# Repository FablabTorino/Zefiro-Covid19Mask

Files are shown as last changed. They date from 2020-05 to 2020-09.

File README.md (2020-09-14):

# Zefiro-Covid19Mask

<p style="text-align: left;"><span style="font-family: Helvetica;"><strong><span style="font-size: 16px;">Edited by:</span><span style="font-size: 18px;">&nbsp;</span></strong></span><span style="font-family: Helvetica; font-size: 14px;">Asja Aulisio,&nbsp;</span><span style="font-size: 14px;"><span style="font-family: Helvetica;">Stella Bellisario, Dario Bortolotti, Eva Vanessa Bruno, Alessandro Campanella, Francesca Cappa, Federico Citarda, Martina Gargiulo Pozzo, Davide Mercenati, Roberto Montarolo, &nbsp;</span></span><span style="font-family: Helvetica; font-size: 14px;">Fabiana Rovera</span></p>
<p style="text-align: left;"><span style="font-family: Helvetica;"><strong><span style="font-size: 16px;">Supervisors:&nbsp;</span></strong><span style="font-size: 14px;">Fabrizio Alessio (Councilor Fablab Torino),&nbsp;</span></span>
    <font face="Helvetica"><span style="font-size: 14px;">Fabrizio Valpreda (Prof. and Scientific director virtuaLAB - Politecnico di Torino),&nbsp;</span></font><span style="font-size: 14px;"><span style="font-family: Helvetica;">Alessandro Dentis&nbsp;</span></span><span style="font-size: 14px;"><span style="font-family: Helvetica;">(Technical manager virtuaLAB -&nbsp;</span></span><span style="font-family: Helvetica; font-size: 14px;">Politecnico di Torino)</span>
</p>

<p style="text-align: left;"><span style="font-family: Helvetica;"><span style="font-size: 16px;"><strong>Contacts</strong></span><span style="font-family: Helvetica; font-size: 16px;"><strong style="font-weight: 700;">: <span style="font-family: Helvetica; font-size: 14px;"></span></strong><span style="font-family: Helvetica; font-size: 14px;"></span><span style="font-family: Helvetica; font-size: 14px;"><a href="mailto:covid@fablabtorino.org,">covid@fablabtorino.org,</a> <span style="font-family: Helvetica;"><a href="mailto:virtualab@polito.it">virtualab@polito.it</a></span></span></span></span></p>

<p>&nbsp;&nbsp;</p>

<a href="https://ibb.co/vPhq9wr">3279467-orig</a>
<a href="https://ibb.co/tzwNXNw">Schermata-2020-05-14-alle-22-59-36</a>

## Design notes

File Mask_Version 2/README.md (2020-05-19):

# FABRIC-FRAME
## FRAME-FACE SHIELD

__Problem__: Now it's just glued    
__Need__: Fixing with mask, reversible, guaranteeing insolation and 3D printing    

## DIFFUSER
__Problem__: Fragile diffuser-valve connection    
__Need__: Improve the connection system with the valve     

- Study of printing parameters and thicknesses. Guarantee resistance with suitable thicknesses. 
- What are the stresses on the frame? Does it need a large thickness or a thin one with designed filling?
- Improve the elastic distribution system.
- Improve printability: problem with printers with a small printing plate.
- Improve ergonomics

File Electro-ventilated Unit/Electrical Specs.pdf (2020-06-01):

# Zefiro

### Descrizione:

Componenti elettriche ed elettroniche necessarie al funzionamento di un respiratore PAPR. Le componenti principali saranno:
- ventole, comprese di motore e soffiante,
- batterie (per l’alimentazione delle ventole e dell’elettronica di controllo),
- sensore di pressione,
- sistema di controllo del voltaggio delle batterie,
- attuatori acustici per segnalazioni,
- attuatori luminosi (LED) per segnalazioni,
- interfaccia di controllo e parametrizzazione del funzionamento

I requisiti principali di funzionamento possono essere descritti con:
- le batterie devono essere adatte ad alimentare motori e elettronica per la durata di un turno di lavoro, tipicamente 8 ore.
In caso non si riesca a soddisfare tale requisito, si deve garantire che le batterie possano essere sostituite in modo agevole e mentre l’operatore indossa il dispositivo.
- i motori devono garantire un flusso di almeno 200 l/m attraverso un filtro FFFP3.
- l’interfaccia di controllo dovrà permettere di modificare la velocità di rotazione del motore, quindi la quantità di aria spinta all’interno della maschera
- il sensore di pressione dovrà essere sensibile alla mancanza di portata minima da parte dei motori
- il sensore di pressione dovrà essere utilizzato come trigger per attivare un allarme luminoso e sonoro in caso di mancanza di portata minima garantita.
- il sistema di misura del voltaggio delle batterie dovrà misurare la carica della batterie e essere utilizzato come trigger per attivare un allarme sonoro e luminoso prima che le batterie si scarichino.

### Descrizione Componenti e loro funzionamenti:

Le componenti principali del dispositivo sono:
1. Batteria
2. motore e soffiante
3. MCU
4. UI:
a. potenziometri
b. bottoni
c. LED (luminoso)
d. Buzzer (acustico)
5. Sensori:
a. Pressione
b. Temperatura
c. Umidità relativa
d. CO2
e. Voltaggio
f. Corrente
6. Logger

Descrizione Funzionamento:

### 6. Logger: Si è deciso di inserire inizialmente un logger per registrare i parametri di

funzionamento durante ogni funzionamento del dispositivo.
I parametri che verranno registrati sono:
Voltaggio batteria, Corrente principale, Velocità rotazione ventola (in 0-255), stato generale, T, P, HR, CO2
La registrazione continua dei parametri è utile nel processo di ricerca e ottimizzazione delle performance del dispositivo.

Alimentazione: si pensa ad una batteria da 12V che alimenti il motore e l’elettronica, la componente elettronica sarà connessa a valle da un circuito di stepdown per portare il voltaggio al corretto valore.

### 2. Motore e Soffiante:

un potenziometro verrà destinato alla regolazione della velocità di rotazione della ventola

TO-DECIDE
Il potenziometro potrebbe decidere:
i. la velocità di rotazione della ventola, quindi mappare in modo lineare la velocità. Questo darebbe all’utilizzatore la possibilità di autoregolarsi la velocità di rotazione, pratica pericolosa e che può portare fuori controllo.
ii. il potenziometro può servire per regolare la velocità massima di rotazione e l’utente in un altro modo può decidere la velocità di rotazione
iii. il potenziometro può servire per regolare la velocità massima di rotazione. La velocità di rotazione della ventola è decisa tramite una funzione di uno o più sensori.

### 5. Sensori

TO-DECIDE
I sensori vengono letti e loggati su data logger.
Altre funzioni?
Potrebbero scaturire degli allarmi?
Quali sono le soglie tipiche di funzionamento? Cosa succede succede se se soglie sono superate?
Allarmi e comportamenti per ogni sensore:
a. Pressione
b. Temperatura
c. Umidità relativa
d. CO2
e. Voltaggio
f. Corrente

UI:
TO-DECIDE
Funzionamenti e scopo delle interfacce
i. potenziometri
ii. bottoni
iii. LED (luminoso)
iv. Buzzer (acustico)

Descrizione del funzionamento del device:
Un interruttore generale alimenta tutto il dispositivo
La soffiante viene controllata dal micro-controllore tramite una funzione di trasferimento ancora da definire.
- Esiste una velocità minima sotto la quale la soffiante, a device acceso, non gira mai per garantire una componente di sicurezza a livello Firmware
- Decidere la funzione di trasferimento per il pilotaggio della soffiante:
- ES: due velocità decise da un pulsante con Vel max decisa dal pot e le due vel sono il 50% e il 100% di tale velocità?
Il micro-controllore legge tutti i sensori e in caso i valori letti siano all’interno dei range decisi pilota la soffiante.

Cosa succede se:
- voltaggio batteria basso?
- pressione bassa?
- pressione alta?
- temperatura bassa?
- temperatura alta?
- HR bassa
- HR alta?
- Sensore di CO2 che range dovrebbe avere

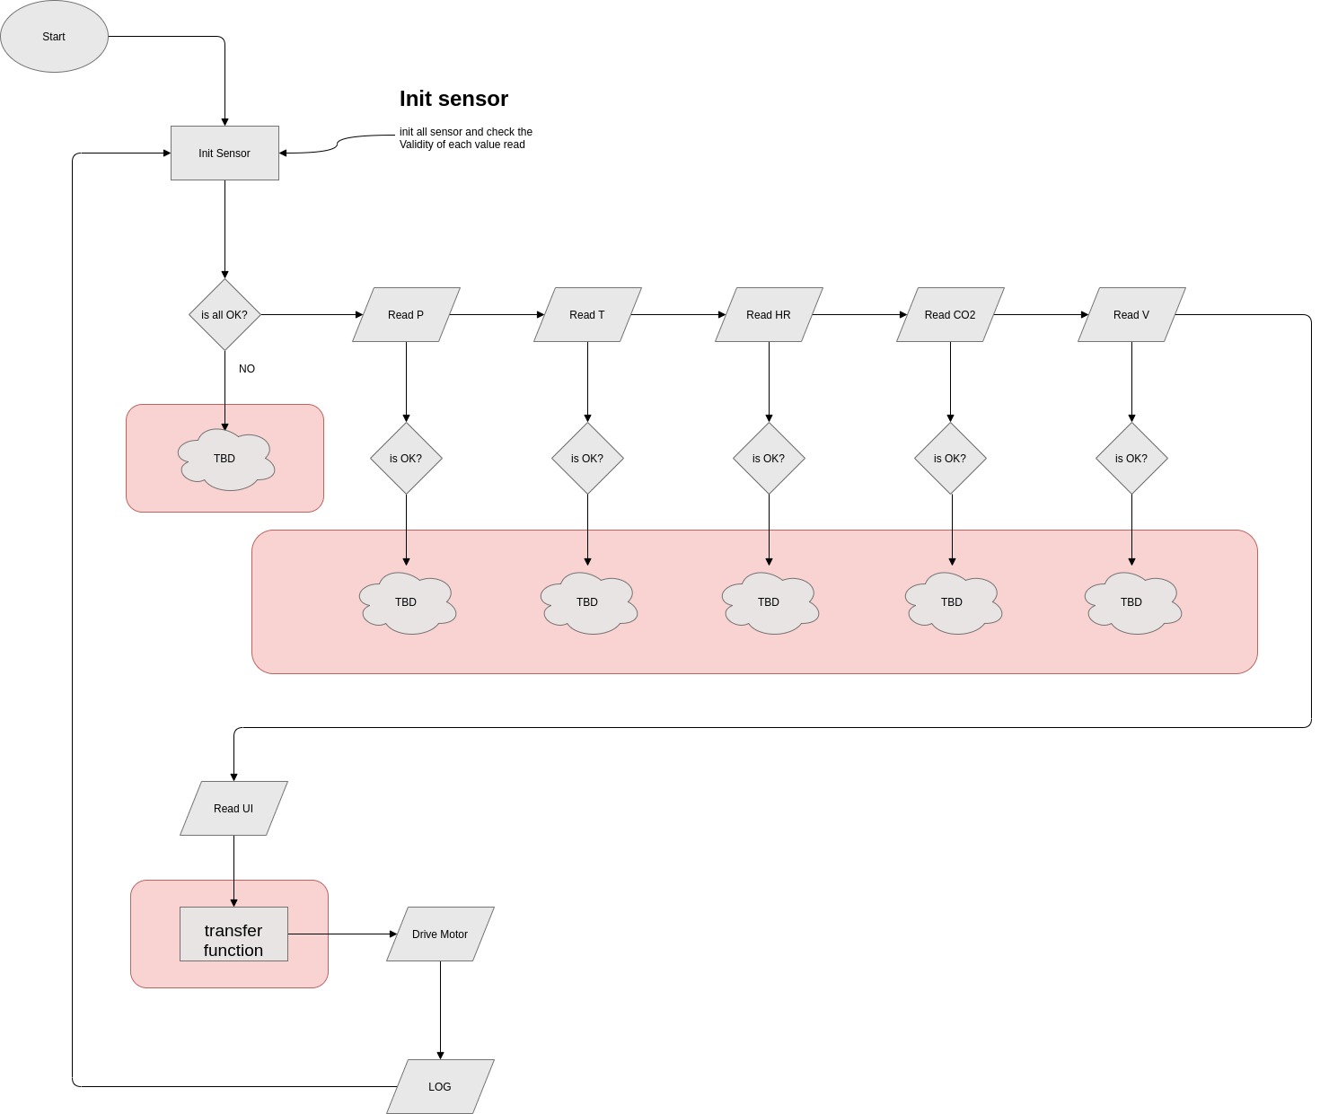
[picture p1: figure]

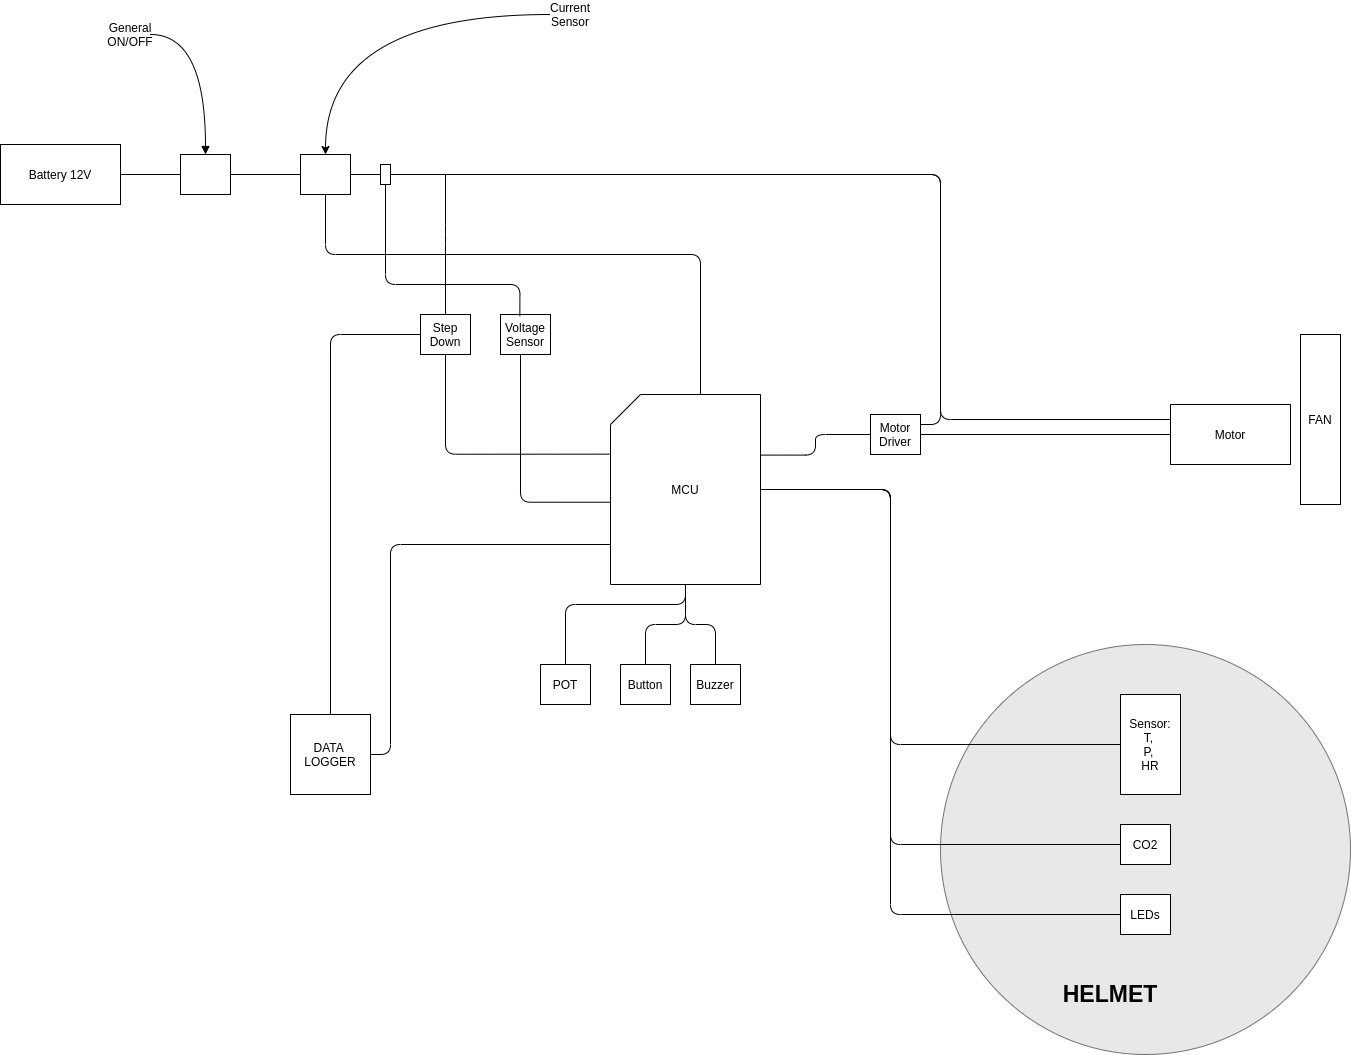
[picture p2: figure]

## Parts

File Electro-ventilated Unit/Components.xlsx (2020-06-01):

 | soluzione A
componenti | link | nome | note | prezzo
motore | https://www.digikey.com/product-detail/en/delta-electronics/BFB0512HH-T50F/603-1475-ND/2560599 |  |  | 15.9$ | https://www.digikey.com/product-detail/en/delta-electronics/BFB0512HH-T50F/603-1475-ND/2560599
soffiante
MCU to Grove | https://www.seeedstudio.com/Base-Shield-V2.html |  | per connettere facilmente | 5.9
MCU controllo | https://www.seeedstudio.com/Seeeduino-V4-2-p-2517.html |  | arduino uno | 6.9
barometro | https://www.seeedstudio.com/Grove-Temperature-Humidity-Pressure-and-Gas-Sensor-for-Arduino-BME680.html | T HR P | sensore di molti parametri, dato il costo potrebbe essere utile tracciarli | 20,5$
driver motore | https://www.seeedstudio.com/Grove-MOSFET.html | mosfet | vin 5V | 3.90 $
sensore voltaggio batteria | https://www.seeedstudio.com/Grove-Voltage-Divider.html | partitore |  | 5,90 $
 | https://www.seeedstudio.com/Grove-10A-DC-Current-Sensor-ACS725-p-2927.html | current sensor |  | 10$
segnale luminoso
segnale sonoro | https://www.seeedstudio.com/Grove-Passive-Buzzer-p-4525.html | buzzer |  | 2.9
ui controllo | https://www.seeedstudio.com/Grove-Dual-Button-p-4529.html | 2 button |  | 2.2
 |  | pot *2
 |  | switch *2
step down | https://www.seeedstudio.com/Adjustable-Step-Down-DC-DC-Converter-1-0V-17V-1-8-p-1717.html |  |  | 3.9$ *2
sensore c02 | https://www.seeedstudio.com/Grove-VOC-and-eCO2-Gas-Sensor-for-Arduino-SGP30.html |  |  | 15.9$
batteria | https://www.amazon.it/docooler-Caricatore-Caricabatterie-Alimentazione-Applicazioni/dp/B07BF4SR6S |  |  | 29.98€
cavi | https://www.seeedstudio.com/Grove-Universal-4-Pin-Buckled-20cm-Cable-5-PCs-pack.html |  | 4 cavi da 20cm * 2 | 5.8
logger | https://www.amazon.it/Melopero-Raspberry-Zero-Starter-Kit/dp/B072LWBL37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 |  |  | 28.5€
sd

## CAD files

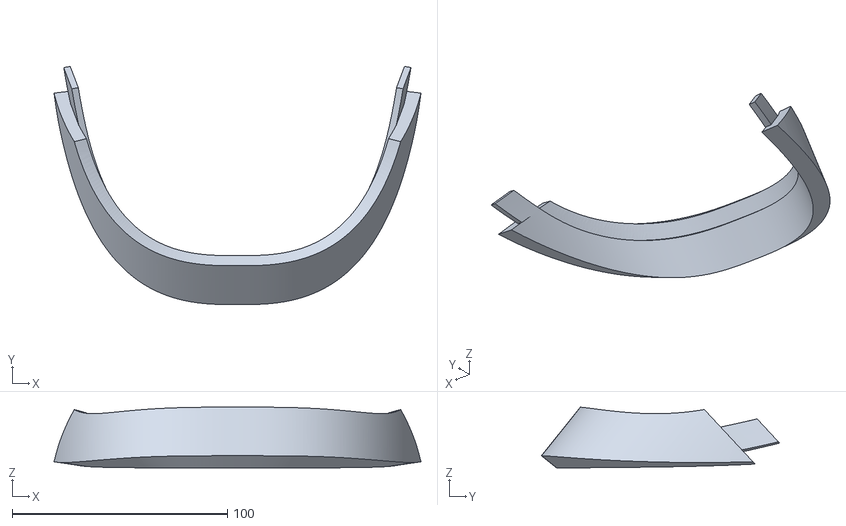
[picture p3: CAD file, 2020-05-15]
Mask_Version 2/STL_Components/Frame 2.stl
170.5 x 110.7 x 28.2

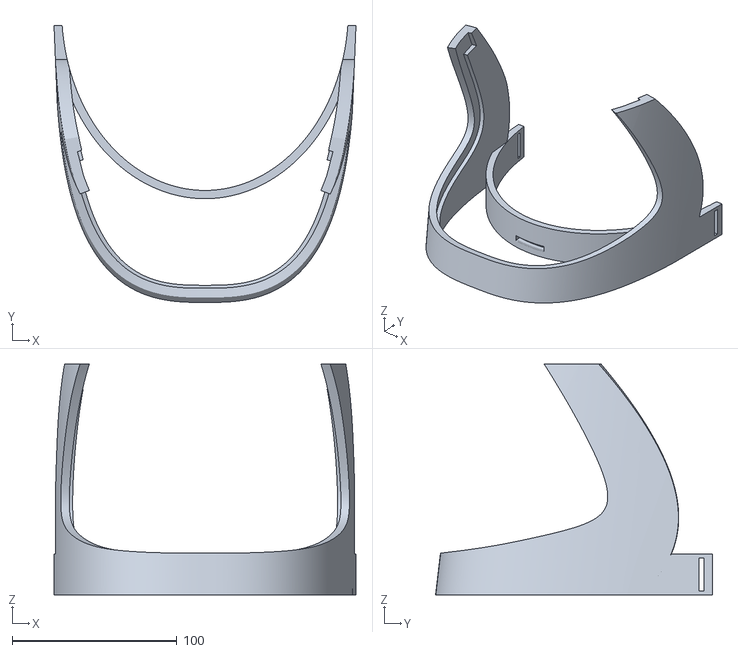
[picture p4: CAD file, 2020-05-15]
Mask_Version 2/STL_Components/Frame 1.stl
183.2 x 168.0 x 140.1

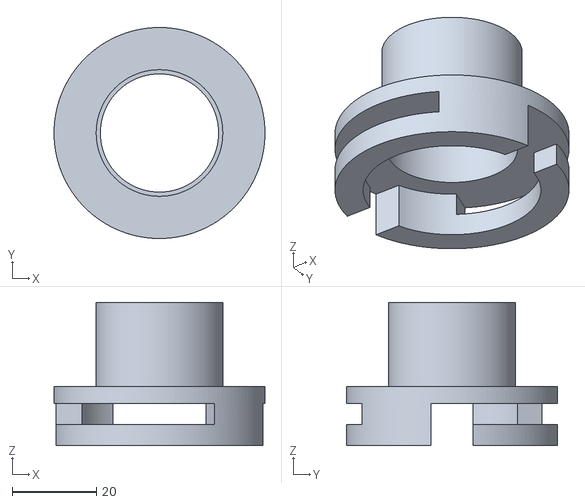
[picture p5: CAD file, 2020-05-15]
Mask_Version 2/STL_Components/Valve.stl
50.0 x 50.0 x 34.0

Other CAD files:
Electro-ventilated Unit/3dm/Adapter 3M-RD40_V5.3dm
Electro-ventilated Unit/3dm/Adapter CPAP-RD40_V5.3dm
